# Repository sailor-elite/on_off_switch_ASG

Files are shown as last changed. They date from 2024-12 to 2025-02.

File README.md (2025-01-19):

# ATTINY13A Automatic Stop And Go Off Switch

This project implements an automatic Stop and Go Off Switch for the AS&G (Auto Stop & Go) system in Mitsubishi ASX and Citroën C4 Aircross. The switch is designed to enhance user convenience by automatically disabling the AS&G system after ignition.

## Features

- **Automatic AS&G System Override**: Automatically disables the AS&G system after time defined by user.
- **Compact Design**: Designed with a small PCB footprint suitable for automotive integration.
- **Low Power Consumption**: Utilizes power-efficient components to minimize current draw.
- **Easy Installation**: Plug-and-play solution compatible with Mitsubishi ASX and Citroën C4 Aircross.

## Components

| Reference | Value | Footprint |
|---|---|---|
| C1, C2 | 100nF/25V | Capacitor_SMD:C_0603_1608Metric |
| D1, D2 | 1N4007 | Diode_SMD:Nexperia_CFP3_SOD-123W |
| K1 | HFD23_005-1ZS | relays:HFD230051ZS |
| Q1 | BC846 | Package_TO_SOT_SMD:SOT-23 |
| R1 | 1k | Resistor_SMD:R_0805_2012Metric |
| U1 | ATtiny13A-P | Package_DIP:DIP-8_W7.62mm |
| U2 | L78L05_SOT89  | Package_TO_SOT_SMD:SOT-89-3_Handsoldering |

## Dependencies
To compile and upload the code for the ATtiny13A, the following tools and libraries are required:
- AVR-GCC
- AVRDUDE
- Make
- USBasp Programmer
## Schematic
<p align="center">
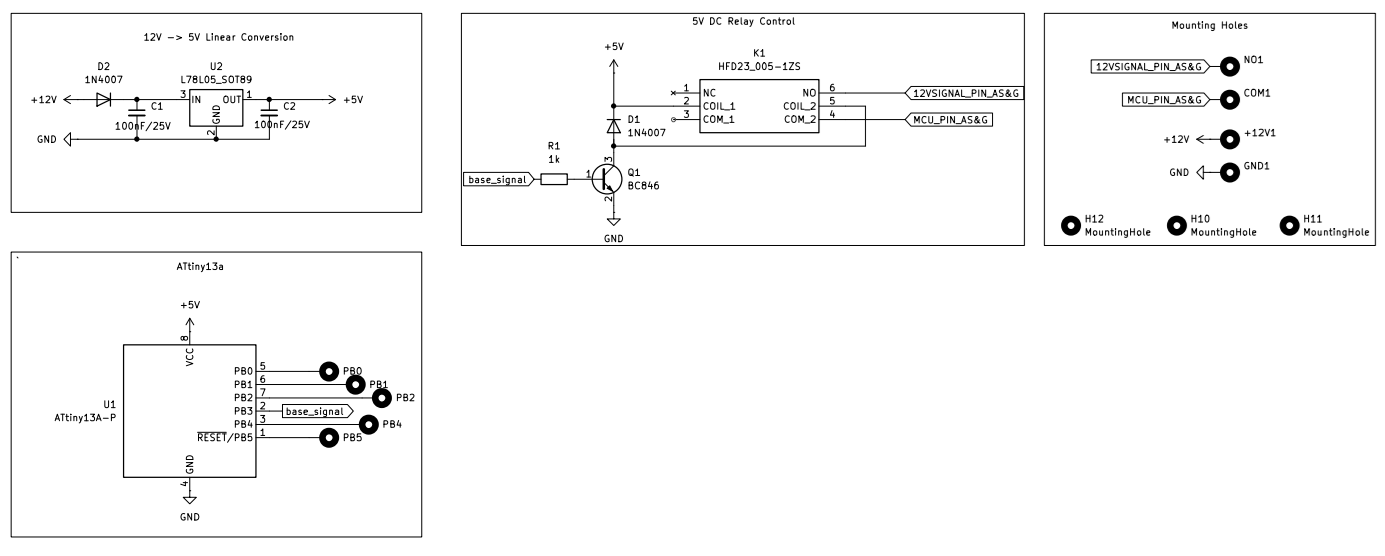
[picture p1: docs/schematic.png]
schematic
  
</p>

## PCB View
<p align="center">
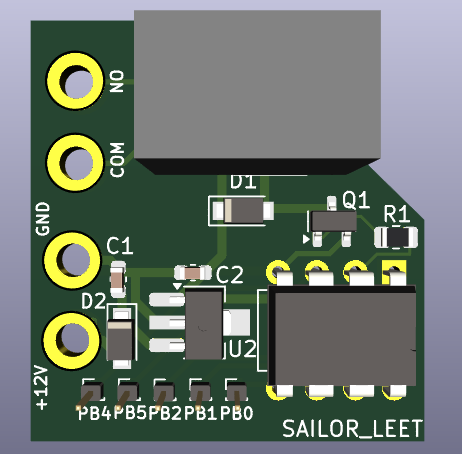
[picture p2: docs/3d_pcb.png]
PCB view
  
</p>

## Casing
<p align="center">
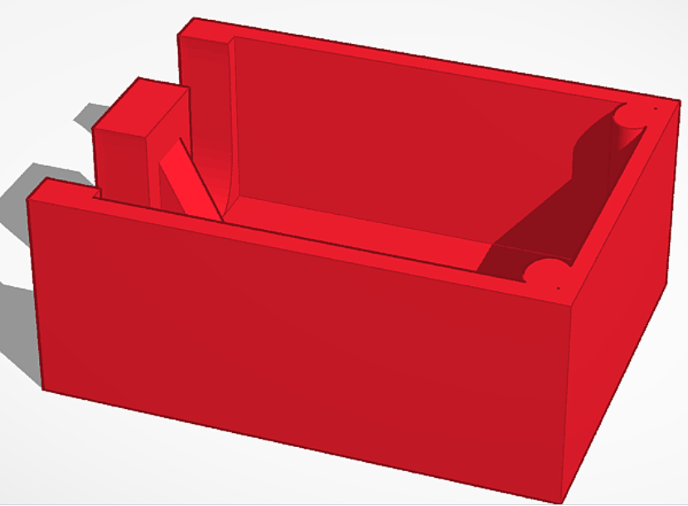
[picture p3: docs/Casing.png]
Casing
  
</p>

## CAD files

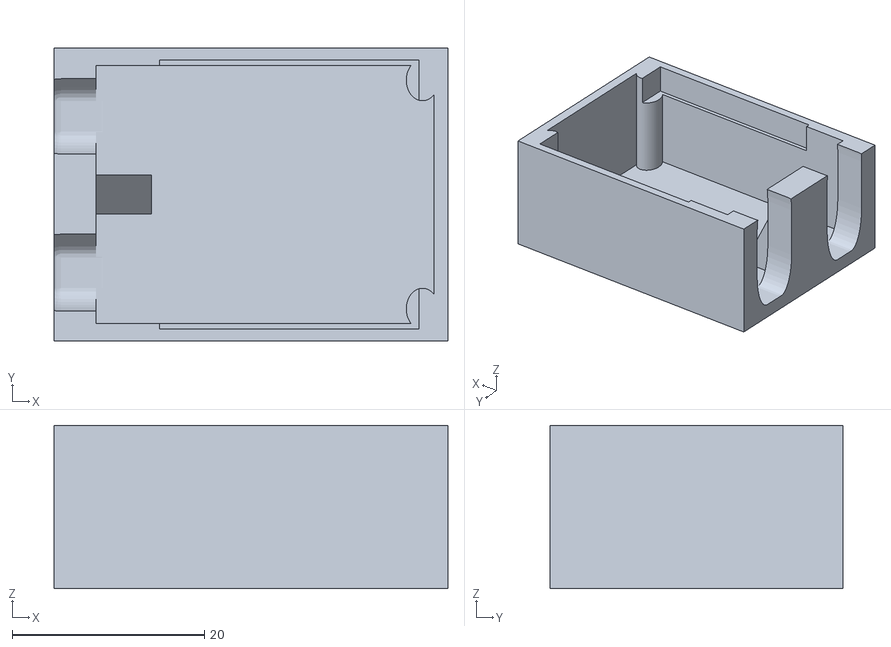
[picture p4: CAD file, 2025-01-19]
docs/Casing.stl
41.0 x 30.5 x 17.0

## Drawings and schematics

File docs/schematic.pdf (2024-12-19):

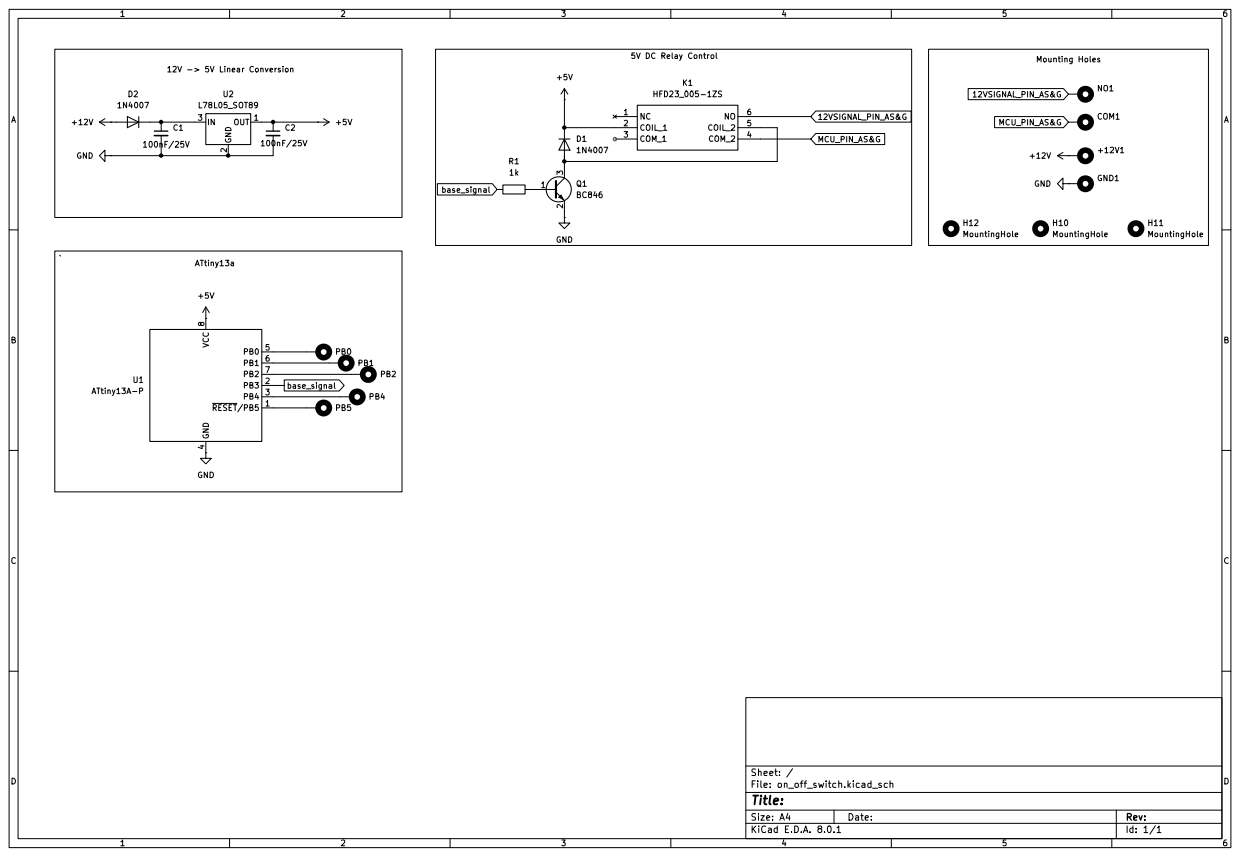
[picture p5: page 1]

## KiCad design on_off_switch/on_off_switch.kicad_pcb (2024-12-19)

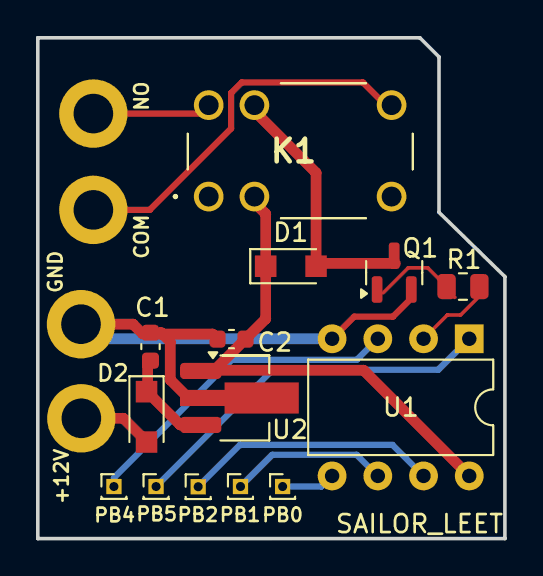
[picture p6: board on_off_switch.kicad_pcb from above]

Board: 2 copper layers, 25.9 x 27.8 mm, 18 parts (0 on the bottom side), 14 nets.

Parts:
+12V: MountingHole_Pad_MP; MountingHole_2.2mm_M2_DIN965_Pad
C1, C2: 100nF/25V; C_0603_1608Metric
COM: MountingHole_Pad_MP; MountingHole_2.2mm_M2_DIN965_Pad
D1, D2: 1N4007; Nexperia_CFP3_SOD-123W
GND: MountingHole_Pad_MP; MountingHole_2.2mm_M2_DIN965_Pad
K1: HFD23_005-1ZS; HFD230051ZS
NO: MountingHole_Pad_MP; MountingHole_2.2mm_M2_DIN965_Pad
PB0, PB1, PB2, PB4, PB5: MountingHole_Pad_MP; PinHeader_1x01_P1.00mm_Vertical
Q1: BC846; SOT-23
R1: 1k; R_0805_2012Metric
U1: ATtiny13A-P; DIP-8_W7.62mm
U2: L78L05_SOT89; SOT-89-3_Handsoldering

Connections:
12VSIGNAL_PIN_AS&G: K1.6 (NO), NO.1
+5V: C2.1, D1.1 (K), K1.2 (COIL_1), U1.8 (VCC), U2.1 (OUT)
+12V: +12V.1, D2.2 (A)
GND: C1.2, C2.2, GND.1, Q1.2 (E), U1.4 (GND), U2.2 (GND)
MCU_PIN_AS&G: COM.1, K1.4 (COM_2)
unnamed: D1.2 (A), K1.5 (COIL_2), Q1.3 (C)
unnamed: C1.1, D2.1 (K), U2.3 (IN)
unnamed: Q1.1 (B), R1.2
unnamed: PB0.1, U1.5 (PB0)
unnamed: PB1.1, U1.6 (PB1)
unnamed: PB2.1, U1.7 (PB2)
unnamed: PB4.1, U1.3 (PB4)
unnamed: PB5.1, U1.1 (~RESET/PB5)
base_signal: R1.1, U1.2 (PB3)

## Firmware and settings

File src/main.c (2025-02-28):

#include <avr/io.h>
#include <avr/interrupt.h>
#include <avr/sleep.h>

#define F_CPU 1200000UL
#define DelayTimeOn 10000
#define DelayTimeOff 1000
#define RelayPin PB3

void Setup_Power_Save()
{
    ADCSRA &= ~(1<<ADEN); //Disable ADC
    ACSR = (1<<ACD); //Disable the analog comparator
    DIDR0 = 0x3F; //Disable digital input buffers on all ADC0-ADC5 pins.
    WDTCR |= (1<<WDP3 )|(0<<WDP2 )|(0<<WDP1)|(1<<WDP0); // Enable watchdog timer interrupts
    DDRB = 0x1F; // Set all pins as outputs
}


// Timer based delay
void delay_ms(uint16_t ms)
{
    TCCR0A = (1 << WGM01);
    TCCR0B = (1 << CS01);
    OCR0A = 149;
    
    uint16_t i;
    for (i = 0; i < ms; i++) {
        TCNT0 = 0;
        while (!(TIFR0 & (1 << OCF0A)));
        TIFR0 |= (1 << OCF0A);
    }

    TCCR0B = 0;
}


// Function to switch Auto Stop & Go
void SwitchASG()
{
    PORTB &= ~_BV(RelayPin);
    delay_ms(DelayTimeOn);
    PORTB |= _BV(RelayPin);
    delay_ms(DelayTimeOff);
    PORTB &= ~_BV(RelayPin);
}

void Enter_Low_Power_Mode()
{
    set_sleep_mode(SLEEP_MODE_PWR_DOWN); // Set as Power - Down
    cli(); // Disable Interrupts
    sleep_enable(); // Enable sleepmode 
    sleep_cpu(); // Enable cpu sleep
}

int main(void)
{
    Setup_Power_Save();
    SwitchASG();
    Enter_Low_Power_Mode();

    while (1);
    return 0;
}

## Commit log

2024-12-17 Added schematic design of PCB
    [on_off_switch.kicad_pcb, on_off_switch.kicad_sch]
2024-12-17 added PCB design
    [on_off_switch.kicad_pcb, on_off_switch.kicad_sch]
2024-12-17 Update README.md
    added PCB view
2024-12-19 Reworked schematics and PCB
    added mounting holes and renamed existing ones.
    [on_off_switch.kicad_pcb, on_off_switch.kicad_sch]
2024-12-19 Schematic and PCB change
    Added reverse polarity protection diode, replaced relay diode with 1n4007, removed mounting holes
    [on_off_switch.kicad_pcb, on_off_switch.kicad_sch]
2024-12-19 Added Gerbers file, modified PCB design
    gerber and drill files, minor PCB changes
    [on_off_switch-B_Cu.gbr, on_off_switch-B_Mask.gbr, on_off_switch-B_Paste.gbr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]
2025-01-19 Added Casing
    [Casing.stl]
2025-02-28 Fix ATtiny13A issue with delay function
    Fix ATtiny13A issue by setting the correct fuse bits:
    - Change LFuse to 0x62 (disable clock division by 8 and disable CKOUT clock output)
    - Change HFuse to 0xFF (disable bootloader and Watchdog Timer)
    [main.c]
